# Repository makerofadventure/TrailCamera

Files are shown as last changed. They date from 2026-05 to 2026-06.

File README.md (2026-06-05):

# TrailCamera

A power-efficient, motion-activated trail camera built with Arduino. This project is designed to sit quietly in the wild, waking up only to capture images when wildlife or movement is detected, and saving those images directly to an SD card.

## How It Works
The camera operates in two distinct modes to make deployment and operation as seamless as possible:

### 1. Setup Mode (Wireless Access Point)
Upon first starting up, the camera broadcasts its own Wi-Fi network, acting as an Access Point. By connecting your phone or laptop to this network, you can access a web interface that provides:
* **Live View:** Stream a live feed from the camera to help you perfectly frame and position your shot in the wild.
* **Gallery & Download:** View and download previously captured wildlife photos directly to your device without removing the SD card.
* **Clear Storage:** Easily wipe the SD card to prepare for a brand-new deployment.
* **Arm Camera:** A button to exit Setup Mode, sync the camera's internal Real-Time Clock (RTC) to your browser's time for accurate photo file timestamps, and put the camera into its ultra-low-power deep sleep mode to begin monitoring.

> **Note:** Take a screenshot of the Setup Mode web interface and save it as `UI_Screenshot.jpg` in this directory to display it here.

!Web Interface UI

### 2. Trail Mode (Deep Sleep)
Once the device is physically deployed and armed via the web interface:
1. **Standby:** The system shuts down its Wi-Fi and enters an ultra-low-power deep sleep mode.
2. **Motion Detection:** A PIR sensor continuously monitors the area for heat/movement signatures.
3. **Wake Up:** Upon detecting motion, the PIR sensor triggers a hardware interrupt, immediately waking the microcontroller from deep sleep.
4. **Capture & Store:** The camera module powers up, captures an image, and writes the file to the SD card.
5. **Sleep:** The system automatically returns to deep sleep to wait for the next trigger.

## Why Deep Sleep?
Trail cameras are typically deployed outdoors and rely completely on battery power for weeks or months at a time. If the processor and camera were running continuously, the batteries would die in a matter of hours. By utilizing **deep sleep**, the microcontroller shuts down non-essential internal clocks and peripherals (like the camera and SD card reader), dropping its power draw to mere microamps. It only consumes significant power for the brief moments it is awake to take a picture, massively extending the battery life of the device.

## Power-On Behavior & Setup Entry
When the camera is cold-booted (power switch turned ON):
1. **Initial Boot Latency (7–10 seconds of silence):** Upon powering on, **the camera will appear completely dead for 7 to 10 seconds** (no LED activity). This is because the PIR sensor requires time to stabilize, during which it holds its output HIGH and pulls **GPIO 12** (the ESP32's flash voltage strapping pin) HIGH. This forces the ESP32 into a silent temporary boot loop. Once the PIR warms up and goes LOW, the ESP32 boots normally. This 7-10 second silent pause is completely normal.
2. **Setup Mode Entry Window (1 second of lit LED):** Immediately after the 7-10 second silent pause, the Flash LED will turn on dimly for **exactly 1 second**. 
   * **To enter Setup Mode (Wi-Fi AP):** You must turn the power switch **OFF while this LED is active (lit)**, and then turn it back ON. On the next boot, the camera will enter Setup Mode and broadcast `TrailCam_Setup`.
   * **To stay in Monitoring Mode:** Do nothing. After the 1-second window, the LED turns off, the camera waits for the PIR sensor to settle, and then enters low-power deep sleep.

## Blink Codes (White Flash LED)
The camera uses the built-in white Flash LED (configured at a very dim brightness to protect your eyes) to indicate its status:
* **1 blink:** Heartbeat logged (hourly timer wake, appends to `heartbeat.txt`).
* **2 blinks:** Photo successfully captured and saved to the SD card.
* **3 blinks:** Motion detected (PIR wakeup trigger).
* **4 blinks:** SD Card mount/save failure.
* **5 blinks:** Webserver setup mode starting (SSID `TrailCam_Setup`).
* **10 fast blinks:** Camera initialization error.
* **1-second solid dim pulse:** Device is entering deep sleep mode.

## Wiring & Pinouts
Wire up the components as detailed below, then compile and upload the software using the Arduino IDE. 

| Component | Pin | Description |
| :--- | :--- | :--- |
| **Power System** | `5V` / `GND`| Powered by 6V (4x AA batteries) connected to the board |
| **PIR Sensor VCC** | `3.3V` | Powered from the ESP32 3.3V pin |
| **PIR Sensor GND** | `GND` | Ground connection |
| **PIR Sensor Out** | `Pin 12` | Hardware interrupt to wake the board from deep sleep |
| **SD Card & Camera**| `Built-in`| Using the ESP32-CAM's onboard micro SD slot (1-bit mode) and camera |

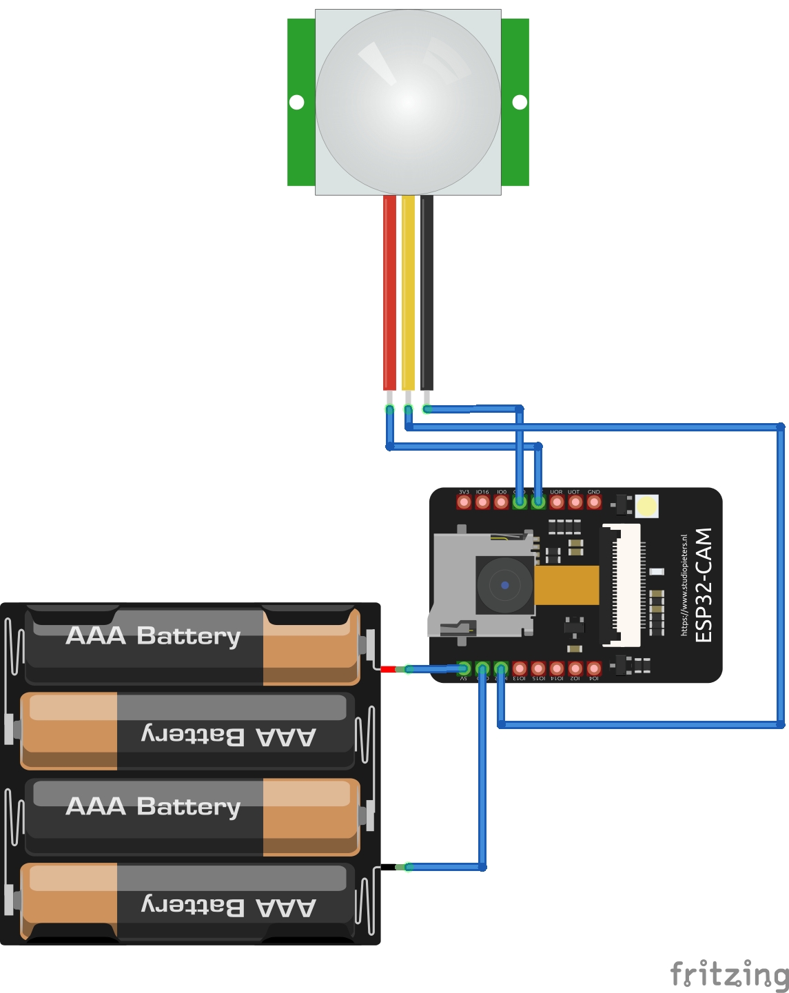
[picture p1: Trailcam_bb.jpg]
Circuit Layout


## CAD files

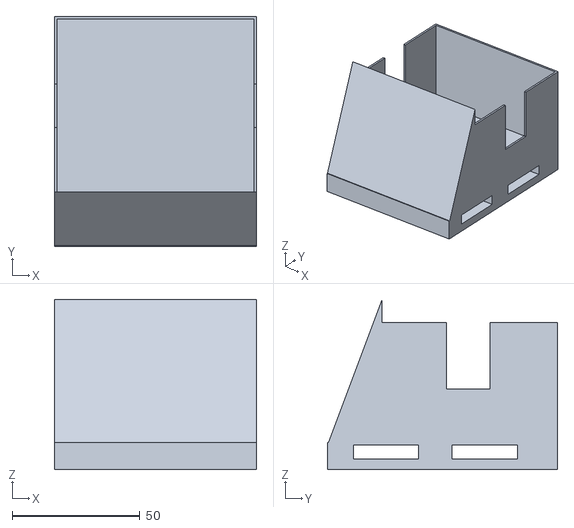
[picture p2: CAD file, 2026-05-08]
TrailcamHousing.stl
79.0 x 90.0 x 66.5

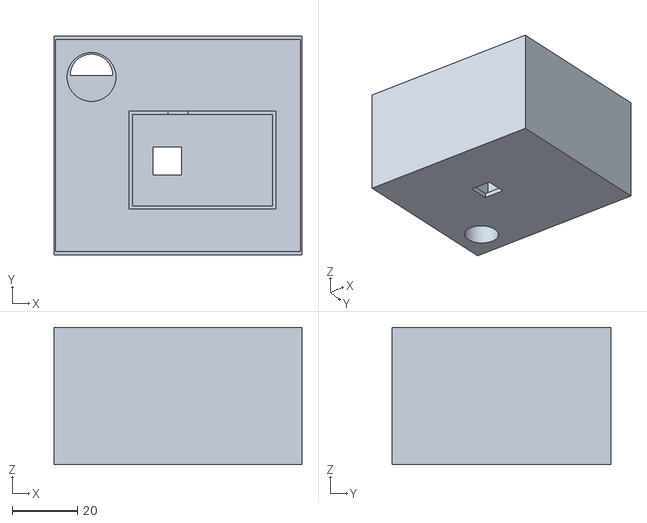
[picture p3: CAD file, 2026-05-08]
TrailCamHousingInner.stl
76.0 x 67.0 x 42.0

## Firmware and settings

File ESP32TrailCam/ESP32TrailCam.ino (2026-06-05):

#include "esp_camera.h"
#include <WiFi.h>
#include <WebServer.h>
#include "SD_MMC.h"
#include <time.h>
#include "soc/soc.h"           // Needed for WRITE_PERI_REG
#include "soc/rtc_cntl_reg.h"  // Needed for RTC_CNTL_BROWN_OUT_REG
#include <esp_wifi.h>
#include <Preferences.h>
#include "driver/rtc_io.h"
// --- (Keep your existing Pin Definitions and Camera Config here) ---
#define PWDN_GPIO_NUM 32
#define RESET_GPIO_NUM -1
#define XCLK_GPIO_NUM 0
#define SIOD_GPIO_NUM 26
#define SIOC_GPIO_NUM 27
#define Y9_GPIO_NUM 35
#define Y8_GPIO_NUM 34
#define Y7_GPIO_NUM 39
#define Y6_GPIO_NUM 36
#define Y5_GPIO_NUM 21
#define Y4_GPIO_NUM 19
#define Y3_GPIO_NUM 18
#define Y2_GPIO_NUM 5
#define VSYNC_GPIO_NUM 25
#define HREF_GPIO_NUM 23
#define PCLK_GPIO_NUM 22
#define PIR_SENSOR_PIN GPIO_NUM_12


#define FLASH_LED_PIN 4

void blinkLED(int count, int durationMs = 200) {
  pinMode(FLASH_LED_PIN, OUTPUT);
  for (int i = 0; i < count; i++) {
    analogWrite(FLASH_LED_PIN, 8);  // Very dim ON (PWM)
    delay(durationMs);
    analogWrite(FLASH_LED_PIN, 0);  // OFF
    if (i < count - 1) {
      delay(durationMs);
    }
  }
  pinMode(FLASH_LED_PIN, INPUT);    // Release pin back to input
}

RTC_DATA_ATTR bool isMonitoring = false;
WebServer server(80);
IPAddress local_ip(10, 11, 12, 13);
IPAddress gateway(10, 11, 12, 13);
IPAddress subnet(255, 255, 255, 0);



// --- Expanded HTML Page ---
const char* htmlPage = R"rawliteral(
<!DOCTYPE html><html><head><meta name="viewport" content="width=device-width, initial-scale=1">
<style>
  body{text-align:center; font-family:sans-serif; background:#f4f4f4; padding:20px;}
  .card{background:white; padding:20px; border-radius:10px; box-shadow:0 2px 10px rgba(0,0,0,0.1); margin-bottom:20px;}
  img{max-width:100%; height:auto; border-radius:5px;}
  .btn{display:block; width:100%; padding:15px; margin:10px 0; border:none; border-radius:5px; font-size:16px; cursor:pointer;}
  .btn-start{background:#27ae60; color:white;}
  .btn-dl{background:#2980b9; color:white;}
  .btn-del{background:#c0392b; color:white;}
</style>
</head><body>
  <div class="card">
    <h2>Live Aim</h2>
    <img src="/capture" id="photo">
    <button class="btn btn-start" onclick="startMonitoring()">START MONITORING</button>
  </div>

  <div class="card">
    <h2>Storage Management</h2>
    <button class="btn btn-dl" onclick="downloadAll()">DOWNLOAD ALL PHOTOS</button>
    <button class="btn btn-del" onclick="confirmDelete()">DELETE ALL PHOTOS</button>
  </div>

<script>
  setInterval(function(){ document.getElementById('photo').src='/capture?v=' + Date.now(); }, 3000);
  
  function startMonitoring() {
    const now = Math.floor(Date.now() / 1000);
    location.href = '/start?t=' + now;
  }

  async function downloadAll() {
    const response = await fetch('/listfiles');
    const files = await response.json();
    if(files.length === 0) { alert("No photos found"); return; }
    
    for (const file of files) {
      const link = document.createElement('a');
      link.href = '/download?file=' + file;
      link.download = file;
      document.body.appendChild(link);
      link.click();
      document.body.removeChild(link);
      await new Promise(r => setTimeout(r, 500)); // Small delay to not crash browser/ESP
    }
  }

  function confirmDelete() {
    if(confirm("Are you sure you want to delete ALL photos from the SD card?")) {
      location.href = '/deleteall';
    }
  }
</script>
</body></html>)rawliteral";

// --- Helper Functions ---

void logHeartbeat() {
  if (!SD_MMC.begin("/sdcard", true)) {
    Serial.println("SD Card Mount Failed (Heartbeat)");
    return;
  }

  time_t now;
  struct tm timeinfo;
  time(&now);
  localtime_r(&now, &timeinfo);

  char timeStr[30];
  strftime(timeStr, sizeof(timeStr), "%Y-%m-%d %H:%M:%S", &timeinfo);

  File file = SD_MMC.open("/heartbeat.txt", FILE_APPEND);
  if (!file) {
    Serial.println("Failed to open heartbeat file");
  } else {
    file.printf("Heartbeat: %s\n", timeStr);
    Serial.printf("Logged heartbeat: %s\n", timeStr);
  }
  file.close();
  SD_MMC.end();
}

void saveToSD(camera_fb_t* fb) {
  // 1. Initialize SD Card in 1-bit mode
  if (!SD_MMC.begin("/sdcard", true)) {
    Serial.println("SD Card Mount Failed");
    blinkLED(4, 300); // 4 slow blinks to show SD card mount failure
    return;
  }

  // 2. Get the current time from the internal RTC
  time_t now;
  struct tm timeinfo;
  time(&now);
  localtime_r(&now, &timeinfo);

  // 3. Create the filename string (e.g., /2026-04-29_10-15-30.jpg)
  char fileName[50];
  strftime(fileName, sizeof(fileName), "/%Y-%m-%d_%H-%M-%S.jpg", &timeinfo);

  // 4. Save the image
  File file = SD_MMC.open(fileName, FILE_WRITE);
  if (!file) {
    Serial.println("Failed to open file for writing");
    blinkLED(4, 300); // 4 slow blinks to show file write failure
  } else {
    file.write(fb->buf, fb->len);
    Serial.printf("Saved photo: %s\n", fileName);
    blinkLED(2, 100); // 2 quick blinks to show success
  }

  // 5. Cleanup
  file.close();
  SD_MMC.end();  // Unmount to ensure data is flushed and saved
}

void handleListFiles() {
  if (!SD_MMC.begin("/sdcard", true)) {
    server.send(500, "text/plain", "SD Fail");
    return;
  }
  File root = SD_MMC.open("/");
  String output = "[";
  File file = root.openNextFile();
  while (file) {
    if (String(file.name()).endsWith(".jpg") || String(file.name()).endsWith(".txt")) {
      if (output != "[") output += ",";
      output += "\"" + String(file.name()) + "\"";
    }
    file = root.openNextFile();
  }
  output += "]";
  server.send(200, "application/json", output);
  SD_MMC.end();
}

void handleDownload() {
  String path = server.arg("file");
  if (!path.startsWith("/")) path = "/" + path;
  if (!SD_MMC.begin("/sdcard", true)) return;
  File file = SD_MMC.open(path, FILE_READ);
  if (!file) {
    server.send(404, "text/plain", "Not Found");
    return;
  }
  if (path.endsWith(".jpg")) {
    server.streamFile(file, "image/jpeg");
  } else {
    server.streamFile(file, "text/plain");
  }
  file.close();
  SD_MMC.end();
}

void handleDeleteAll() {
  if (!SD_MMC.begin("/sdcard", true)) return;
  File root = SD_MMC.open("/");
  File file = root.openNextFile();
  while (file) {
    String filename = String(file.name());
    file.close();  // Close before deleting
    SD_MMC.remove("/" + filename);
    file = root.openNextFile();
  }
  SD_MMC.end();
  server.send(200, "text/html", "All files deleted. <a href='/'>Back</a>");
}


void setup() {
  WRITE_PERI_REG(RTC_CNTL_BROWN_OUT_REG, 0);  // Disable brownout detector
  Serial.begin(115200);
  pinMode(FLASH_LED_PIN, INPUT);              // Keep flash LED as high-impedance INPUT by default

  esp_sleep_wakeup_cause_t wakeup_reason = esp_sleep_get_wakeup_cause();
  
  if (wakeup_reason == ESP_SLEEP_WAKEUP_TIMER) {
    isMonitoring = true;
    Serial.println("Wake: Hourly Heartbeat");
    blinkLED(1, 200); // 1 single blink for heartbeat
    logHeartbeat();
    sleepNow(); // Go back to sleep immediately after heartbeat
  } 
  else if (wakeup_reason == ESP_SLEEP_WAKEUP_EXT0) {
    isMonitoring = true;
    Serial.println("Wake: Motion Detected");
    blinkLED(3, 100); // 3 quick blinks for motion detection
    // Continue to camera initialization below
  } 
  else {
    Serial.println("Wake: First Boot / Manual Reset");
    Preferences preferences;
    preferences.begin("trailcam", false);
    bool wasSet = preferences.getBool("monitoring", false);
    if (wasSet) {
      Serial.println("Trailcam flag was set. Clearing temporarily...");
      preferences.putBool("monitoring", false);

      // Turn on white LED dimly to indicate the 1-second power-off window
      pinMode(FLASH_LED_PIN, OUTPUT);
      analogWrite(FLASH_LED_PIN, 15);   // Dim ON
      delay(1000);
      analogWrite(FLASH_LED_PIN, 0);    // OFF
      pinMode(FLASH_LED_PIN, INPUT);

      Serial.println("1 second elapsed without power-off. Resetting trailcam flag...");
      preferences.putBool("monitoring", true);
      isMonitoring = true;
      preferences.end();

      // Wait for PIR sensor to settle (go LOW) after power-on so it doesn't immediately trigger a photo
      pinMode(PIR_SENSOR_PIN, INPUT_PULLDOWN);
      int timeout = 150; // 15 seconds max timeout
      while (digitalRead(PIR_SENSOR_PIN) == HIGH && timeout > 0) {
        delay(100);
        timeout--;
      }
      sleepNow();
    } else {
      Serial.println("Trailcam flag was not set. Entering webserver setup mode...");
      isMonitoring = false;
      preferences.end();
    }
  }

  // 2.  Camera Configuration
  camera_config_t config;
  config.ledc_channel = LEDC_CHANNEL_0;
  config.ledc_timer = LEDC_TIMER_0;
  config.pin_d0 = Y2_GPIO_NUM;
  config.pin_d1 = Y3_GPIO_NUM;
  config.pin_d2 = Y4_GPIO_NUM;
  config.pin_d3 = Y5_GPIO_NUM;
  config.pin_d4 = Y6_GPIO_NUM;
  config.pin_d5 = Y7_GPIO_NUM;
  config.pin_d6 = Y8_GPIO_NUM;
  config.pin_d7 = Y9_GPIO_NUM;
  config.pin_xclk = XCLK_GPIO_NUM;
  config.pin_pclk = PCLK_GPIO_NUM;
  config.pin_vsync = VSYNC_GPIO_NUM;
  config.pin_href = HREF_GPIO_NUM;
  config.pin_sscb_sda = SIOD_GPIO_NUM;
  config.pin_sscb_scl = SIOC_GPIO_NUM;
  config.pin_pwdn = PWDN_GPIO_NUM;
  config.pin_reset = RESET_GPIO_NUM;
  config.xclk_freq_hz = 20000000;
  config.pixel_format = PIXFORMAT_JPEG;
  config.frame_size = FRAMESIZE_VGA;
  config.jpeg_quality = 10;
  config.fb_count = 1;
  esp_err_t err = esp_camera_init(&config);
  if (err != ESP_OK) {
    Serial.printf("Camera init failed with error 0x%x", err);
    blinkLED(10, 50); // 10 extremely fast blinks to show camera error
    // If monitoring, we still want to log that we woke up but failed
    if (isMonitoring) {
        logHeartbeat(); 
        sleepNow();
    }
    return;
  }

  sensor_t* s = esp_camera_sensor_get();
  s->set_framesize(s, FRAMESIZE_VGA);

  if (!isMonitoring) {
    WiFi.softAPConfig(local_ip, gateway, subnet);
    WiFi.softAP("TrailCam_Setup", "2efdaf4b59");
    esp_wifi_set_ps(WIFI_PS_NONE);
    // Routes
    server.on("/", HTTP_GET, []() {
      server.send(200, "text/html", htmlPage);
    });
    server.on("/capture", HTTP_GET, []() {
      camera_fb_t* fb = esp_camera_fb_get();

      if (!fb) {
        Serial.println("No FB");
        server.send(500, "text/plain", "Capture Failed");
        return;
      }
      server.send_P(200, "image/jpeg", (const char*)fb->buf, fb->len);
      esp_camera_fb_return(fb);
    });
    server.on("/listfiles", HTTP_GET, handleListFiles);
    server.on("/download", HTTP_GET, handleDownload);
    server.on("/deleteall", HTTP_GET, handleDeleteAll);
    server.on("/start", HTTP_GET, []() {
      if (server.hasArg("t")) {
        uint32_t timestamp = server.arg("t").toInt();

        // 2. Update the ESP32 internal RTC
        struct timeval tv;
        tv.tv_sec = timestamp;
        tv.tv_usec = 0;
        settimeofday(&tv, NULL);

        Serial.printf("Time synced to: %u\n", timestamp);
      }
      isMonitoring = true;

      // Save trailcam flag to NVS so it persists across power cycles
      Preferences preferences;
      preferences.begin("trailcam", false);
      preferences.putBool("monitoring", true);
      preferences.end();

      server.send(200, "text/plain", "Monitoring starting...");
      delay(1000);
      sleepNow();
    });

    server.begin();
    Serial.println("WiFi Server Started");
    blinkLED(5, 100); // 5 fast blinks to show setup mode AP/server is running
  } else {
 
    s->set_whitebal(s, 1);       // Enable AWB
    s->set_wb_mode(s, 0);        // 0: Auto, 1: Sunny, 2: Cloudy...
    s->set_exposure_ctrl(s, 1);  // Enable AEC

    camera_fb_t* fb;
    //10 lowres shots to get AWB right
    for (int x = 0; x < 4; x++) {
      fb = esp_camera_fb_get();
      if (fb){
        esp_camera_fb_return(fb);}
    }

    fb = esp_camera_fb_get();
    if (fb) {
      // Wait for the PIR sensor to go LOW (settle) before mounting the SD card
      // to prevent any signal transitions on GPIO 12 during SD card initialization.
      pinMode(PIR_SENSOR_PIN, INPUT_PULLDOWN);
      int settleTimeout = 50; // 5 seconds max timeout
      while (digitalRead(PIR_SENSOR_PIN) == HIGH && settleTimeout > 0) {
        delay(100);
        settleTimeout--;
      }

      saveToSD(fb);
      esp_camera_fb_return(fb);
    } else {
      Serial.println("Error - no Image in fb");
    }
 
    delay(5000);  // Wait a bit between shots
    sleepNow();
  }
}


void sleepNow() {
  // Indication that we are about to enter sleep: 1-second dim pulse
  pinMode(FLASH_LED_PIN, OUTPUT);
  analogWrite(FLASH_LED_PIN, 4); // Very dim pulse
  delay(1000);
  analogWrite(FLASH_LED_PIN, 0);
  pinMode(FLASH_LED_PIN, INPUT);  // Release pin

  // Prepare for Sleep
  esp_sleep_enable_ext0_wakeup((gpio_num_t)PIR_SENSOR_PIN, 1);

  // Disable internal pull-up and enable internal pull-down on the PIR pin during deep sleep
  // to keep the pin LOW when the diode is blocked, preventing false triggers.
  rtc_gpio_pullup_dis((gpio_num_t)PIR_SENSOR_PIN);
  rtc_gpio_pulldown_en((gpio_num_t)PIR_SENSOR_PIN);

  // Wake every hour (3600 seconds) to log heartbeat
  uint64_t sleepTime = 3600ULL * 1000000ULL; 
  esp_sleep_enable_timer_wakeup(sleepTime);

  Serial.println("Entering Deep Sleep");
  esp_deep_sleep_start();
}

int lastCount = 0;

void loop() {
  if (!isMonitoring) {
    server.handleClient();

    // Check how many devices are connected to the AP
    int currentCount = WiFi.softAPgetStationNum();

    if (currentCount > lastCount) {
      Serial.printf(">>> Client Connected! Total: %d\n", currentCount);
      lastCount = currentCount;
    } else if (currentCount < lastCount) {
      Serial.printf("<<< Client Disconnected. Total: %d\n", currentCount);
      lastCount = currentCount;
    }
  }
}

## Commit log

2026-05-10 Modved into own dir as per Arduino
2026-06-05 Updated move to Pin 12
